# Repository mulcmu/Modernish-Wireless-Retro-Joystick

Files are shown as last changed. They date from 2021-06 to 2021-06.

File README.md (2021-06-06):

# Modernish-Wireless-Retro-Joystick
 Wii Remote & ESP32 based wireless joystick interface for Atari-style joysticks.

## Goals & Objectives:

- Support for 2 Atari style joystick DB-9 connections.  Directions, Trigger, and two analog (variable resistance) values.
- Use Wiimote, Nunchuk , gamepad for input devices.  Configurable input setup options to accommodate different homebrew hardware.  (Like Wiimote tilt sensor used like paddle controller rotation.)
- Increase distance of busy little hands from vintage hardware.

## Current Status:

See build log on [hackaday.io](https://hackaday.io/project/179786-modernish-wireless-retro-joystick)

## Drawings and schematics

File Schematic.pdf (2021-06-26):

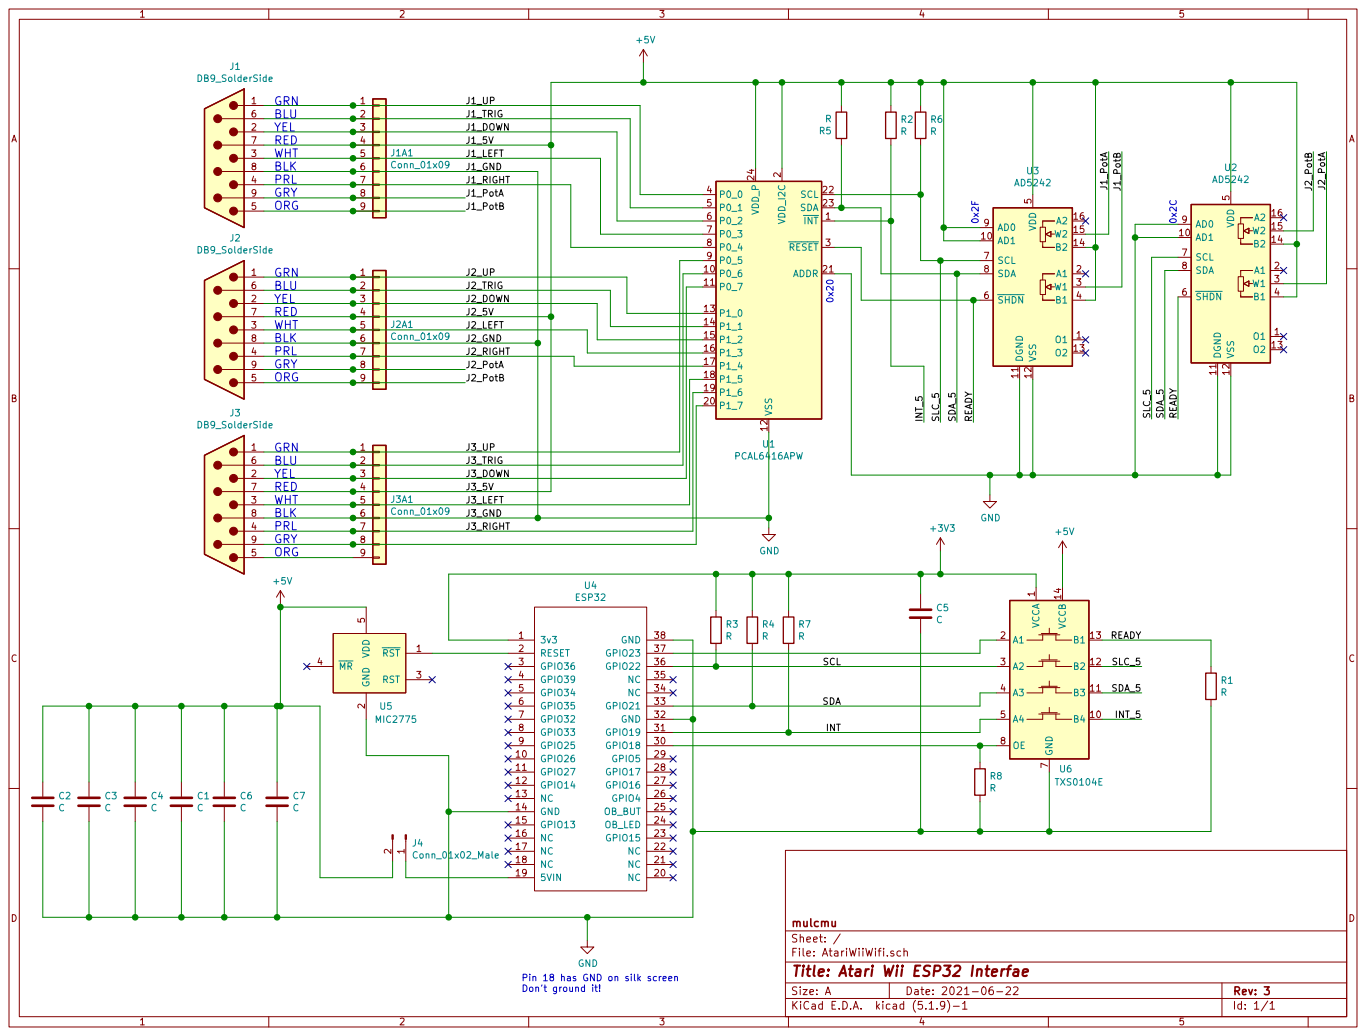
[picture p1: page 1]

J1_DOWN J1_5V

J1_LEFT J1_GND

GRN
BLU
YEL RED WHT BLK

J2_DOWN J2_5V

J2_LEFT J2_GND

J3_DOWN | GND 123456789

J3_GND

File: AtariWiiWifi.sch Sheet: / mulcmu C6 C

Id: 1/1 Title: Atari Wii ESP32 Interfae

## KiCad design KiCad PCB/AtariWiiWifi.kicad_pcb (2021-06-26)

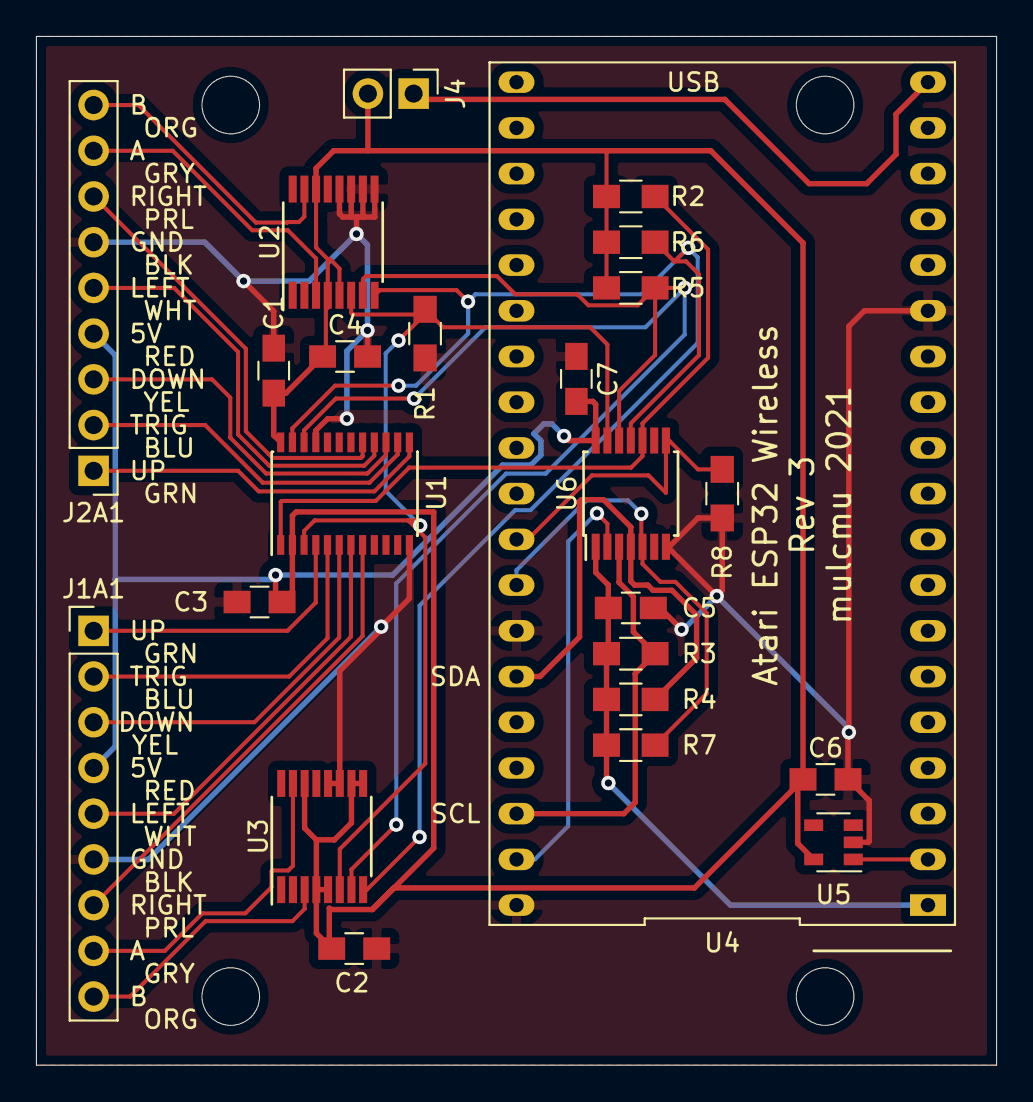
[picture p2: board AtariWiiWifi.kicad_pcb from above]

Board: 2 copper layers, 53.3 x 57.1 mm, 24 parts (0 on the bottom side), 28 nets.

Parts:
C1, C2, C3, C4, C5, C6, C7: C; C_0805_HandSoldering
J1A1, J2A1: Conn_01x09; Pin_Header_Straight_1x09_Pitch2.54mm
J4: Conn_01x02_Male; Pin_Header_Straight_1x02_Pitch2.54mm
R1, R2, R3, R4, R5, R6, R7, R8: R; R_0805_HandSoldering
U1: PCAL6416APW; TSSOP-24_4.4x7.8mm_Pitch0.65mm
U2, U3: AD5242; TSSOP-16_4.4x5mm_Pitch0.65mm
U4: ESP32; DIP-38_900_ELL
U5: MIC2775; SOT-23-5
U6: TXS0104E; TSSOP-14_4.4x5mm_Pitch0.65mm

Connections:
+3V3: C5.1, R3.1, R4.1, R7.1, U4.1, U6.1
+5V: C1.1, C2.1, C3.1, C4.1, C6.1, C7.1, J1A1.4, J2A1.4, J4.2, R2.1, R5.2, R6.1, U1.2, U1.24, U2.4, U2.5, U2.14, U3.4, U3.5, U3.9, U3.10, U3.14, U5.5, U6.14
/INT: R7.2, U4.31, U6.5
/INT_5: R2.2, U1.1, U6.10
/J1_DOWN: J1A1.3, U1.6
/J1_LEFT: J1A1.5, U1.7
/J1_PotA: J1A1.8, U3.15
/J1_PotB: J1A1.9, U3.3
/J1_RIGHT: J1A1.7, U1.8
/J1_TRIG: J1A1.2, U1.5
/J1_UP: J1A1.1, U1.4
/J2_DOWN: J2A1.3, U1.15
/J2_LEFT: J2A1.5, U1.16
/J2_PotA: J2A1.8, U2.3
/J2_PotB: J2A1.9, U2.15
/J2_RIGHT: J2A1.7, U1.17
/J2_TRIG: J2A1.2, U1.14
/J2_UP: J2A1.1, U1.13
/READY: R1.1, U1.3, U2.6, U3.6, U6.13
/SCL: R3.2, U4.36, U6.3
/SDA: R4.2, U4.33, U6.4
/SDA_5: R5.1, U1.23, U2.8, U3.8, U6.11
/SLC_5: R6.2, U1.22, U2.7, U3.7, U6.12
GND: C1.2, C2.2, C3.2, C4.2, C5.2, C6.2, C7.2, J1A1.6, J2A1.6, R1.2, R8.2, U1.12, U1.21, U2.9, U2.10, U2.11, U2.12, U3.11, U3.12, U4.14, U4.32, U4.38, U5.2, U6.7
unnamed: J4.1, U4.19
unnamed: R8.1, U4.30, U6.8
unnamed: U4.2, U5.1
unnamed: U4.37, U6.2

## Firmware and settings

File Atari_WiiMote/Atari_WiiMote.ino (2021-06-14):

#include <Wire.h> //include Wire.h library
#include <esp_types.h>

#include "ESP32Wiimote.h"
ESP32Wiimote wiimote;


#include <atomic>
using namespace std;

//i2c addresses
#define AD5242_J1_ADDRESS 0x2F
#define AD5242_J2_ADDRESS 0x2C
#define PCAL6416A_ADDRESS 0x20

//i2c commands/registers
#define AS524X_RDAC0         0x00
#define AS524X_RDAC1         0x80
#define PCAL6416A_OUTPUT_CFG 0x4F
#define PCAL6416A_DIRECTION  0x06
#define PCAL6416A_OUTPUT     0x02

byte error=0;
uint8_t i=0;
unsigned long t=0;

std::atomic<std::uint8_t> J1_btn;
std::atomic<std::uint8_t> J1_PotA;
std::atomic<std::uint8_t> J1_PotB;

std::atomic<std::uint8_t> J2_btn;
std::atomic<std::uint8_t> J2_PotA;
std::atomic<std::uint8_t> J2_PotB;


TaskHandle_t i2c_taskHandle;


//WiiMote buttons defined for vertical orientation
//Add  _H_ for horizonal orientation
#define BUTTON_H_DOWN     BUTTON_LEFT
#define BUTTON_H_UP       BUTTON_RIGHT
#define BUTTON_H_LEFT     BUTTON_UP
#define BUTTON_H_RIGHT    BUTTON_DOWN

//PCAL6416A button mapping
#define PCAL6416A_UP     0b00000001
#define PCAL6416A_DOWN   0b00000100
#define PCAL6416A_LEFT   0b00001000
#define PCAL6416A_RIGHT  0b00010000
#define PCAL6416A_TRIGR  0b00000010

void setup()
{
 J1_btn=0;
 J1_PotA=0;
 J1_PotB=0;
 J2_btn=0;
 J2_PotA=0;
 J2_PotB=0;

 
  //power up delay.
  delay(250);
  
  Wire.begin(); // Wire communication begin
  
  Serial.begin(115200); 
  //while (!Serial); // Waiting for Serial Monitor

  Serial.println("Atari WiiMote test code.");
  
  //Configure outputs as open-drain (default is push-pull)
  Wire.beginTransmission(PCAL6416A_ADDRESS);
  Wire.write(PCAL6416A_OUTPUT_CFG); 
  Wire.write(0b00000011);
  Wire.endTransmission();

  delay(100);

  //Configure P0.0 to P0.4 and P1.0 to P1.4 as outputs
  Wire.beginTransmission(PCAL6416A_ADDRESS);
  Wire.write(PCAL6416A_DIRECTION); 
  Wire.write(0b11100000);  //Port 0:  1 input, 0 output
  Wire.write(0b11100000);  //Port 1:  
  Wire.endTransmission();
  
  //create a task that will process i2c on core 0
  xTaskCreatePinnedToCore(
                    i2c_loop,       /* Task function. */
                    "i2c Loop",     /* name of task. */
                    10000,          /* Stack size of task */
                    NULL,            /* parameter of the task */
                    1,              /* priority of the task */
                    &i2c_taskHandle,/* Task handle to keep track of created task */
                    0);             /* pin task to core 0 */

    wiimote.init();
    //wiimote.addFilter(ACTION_IGNORE, FILTER_ACCEL); // optional
 
}

//Standard loop handles wiiMote on Core 1
void loop()
{
    wiimote.task();
  if (wiimote.available() > 0) 
    {
      ButtonState  button  = wiimote.getButtonState();
      
      (button & BUTTON_H_UP)    ?    J1_btn |= PCAL6416A_UP     :  J1_btn &= ~PCAL6416A_UP;
      (button & BUTTON_H_DOWN)  ?    J1_btn |= PCAL6416A_DOWN   :  J1_btn &= ~PCAL6416A_DOWN;
      (button & BUTTON_H_LEFT)  ?    J1_btn |= PCAL6416A_LEFT   :  J1_btn &= ~PCAL6416A_LEFT;
      (button & BUTTON_H_RIGHT) ?    J1_btn |= PCAL6416A_RIGHT  :  J1_btn &= ~PCAL6416A_RIGHT;
      (button & BUTTON_TWO)     ?    J1_btn |= PCAL6416A_TRIGR  :  J1_btn &= ~PCAL6416A_TRIGR;
      
      J2_btn.store(J1_btn.load());

      

      if (button & BUTTON_HOME) {
        J1_PotA = 128;
        J1_PotB = 128;
        J2_PotA = 128;
        J2_PotB = 128;
      }

      if (J1_PotA < 253 && button & BUTTON_PLUS) {
        J1_PotA++;
        J1_PotB++;
        J2_PotA++;
        J2_PotB++;
      }

      if (J1_PotA > 3 && button & BUTTON_MINUS){
        J1_PotA--;
        J1_PotB--;
        J2_PotA--;
        J2_PotB--;
      }

    Serial.println(J1_btn);
    Serial.println(J1_PotA);

      
    }

}



void wiiMote_Debug(void)  {
  if (wiimote.available() > 0) 
    {
        ButtonState  button  = wiimote.getButtonState();
        AccelState   accel   = wiimote.getAccelState();
        NunchukState nunchuk = wiimote.getNunchukState();

        if (1)
        {
            char ca     = (button & BUTTON_A)     ? 'A' : '.';
            char cb     = (button & BUTTON_B)     ? 'B' : '.';
            char cc     = (button & BUTTON_C)     ? 'C' : '.';
            char cz     = (button & BUTTON_Z)     ? 'Z' : '.';
            char c1     = (button & BUTTON_ONE)   ? '1' : '.';
            char c2     = (button & BUTTON_TWO)   ? '2' : '.';
            char cminus = (button & BUTTON_MINUS) ? '-' : '.';
            char cplus  = (button & BUTTON_PLUS)  ? '+' : '.';
            char chome  = (button & BUTTON_HOME)  ? 'H' : '.';
            char cleft  = (button & BUTTON_LEFT)  ? '<' : '.';
            char cright = (button & BUTTON_RIGHT) ? '>' : '.';
            char cup    = (button & BUTTON_UP)    ? '^' : '.';
            char cdown  = (button & BUTTON_DOWN)  ? 'v' : '.';
      
            Serial.printf("button: %05x = ", (int)button);
            Serial.print(ca);
            Serial.print(cb);
            Serial.print(cc);
            Serial.print(cz);
            Serial.print(c1);
            Serial.print(c2);
            Serial.print(cminus);
            Serial.print(chome);
            Serial.print(cplus);
            Serial.print(cleft);
            Serial.print(cright);
            Serial.print(cup);
            Serial.print(cdown);
            Serial.printf(", wiimote.axis: %3d/%3d/%3d", accel.xAxis, accel.yAxis, accel.zAxis);
            Serial.printf(", nunchuk.axis: %3d/%3d/%3d", nunchuk.xAxis, nunchuk.yAxis, nunchuk.zAxis);
            Serial.printf(", nunchuk.stick: %3d/%3d\n", nunchuk.xStick, nunchuk.yStick);
        }
    }
}




//i2c loop runs on core 0
void i2c_loop( void * pvParameters ){
  //Serial.print("i2c running on core ");
  //Serial.println(xPortGetCoreID());

  for(;;){
    Wire.beginTransmission(AD5242_J1_ADDRESS);
    Wire.write(AS524X_RDAC0);
    Wire.write(J1_PotA);
    Wire.endTransmission();
    
    Wire.beginTransmission(AD5242_J1_ADDRESS);
    Wire.write(AS524X_RDAC1);
    Wire.write(J1_PotB);
    Wire.endTransmission();

      
    Wire.beginTransmission(AD5242_J2_ADDRESS);
    Wire.write(AS524X_RDAC0);
    Wire.write(J2_PotA);
    Wire.endTransmission();

    
    Wire.beginTransmission(AD5242_J2_ADDRESS);
    Wire.write(AS524X_RDAC1);
    Wire.write(J2_PotB);
    Wire.endTransmission();

    Wire.beginTransmission(PCAL6416A_ADDRESS);
    Wire.write(PCAL6416A_OUTPUT); //Output Register
    Wire.write(~J1_btn);  //Port 0
    Wire.write(~J2_btn);  //Port 1  
    Wire.endTransmission();

  }
}

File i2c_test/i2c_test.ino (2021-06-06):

#include <Wire.h> //include Wire.h library

#define AD5242_J1_ADDRESS 0x2F
#define AD5242_J2_ADDRESS 0x2C
#define PCAL6416A_ADDRESS 0x20

#define AS524X_RDAC0    0x00
#define AS524X_RDAC1    0x80

byte error=0;

uint8_t i=0;

unsigned long t=0;

void setup()
{
  Wire.begin(); // Wire communication begin
  
  Serial.begin(115200); 
  while (!Serial); // Waiting for Serial Monitor

  Serial.println("i2c test code.");

  //Configure P0.0 to P0.4 and P1.0 to P1.4 as outputs
  Wire.beginTransmission(PCAL6416A_ADDRESS);
  Wire.write(0x06); //Direction Register
  Wire.write(0b11100000);  //Port 0:  1 input, 0 output
  Wire.write(0b11100000);  //Port 1:  
  //Serial.println(Wire.endTransmission());

 
}

void loop()
{

  t=millis();

  for(i=0; i<255; i++) {
  
    Wire.beginTransmission(AD5242_J1_ADDRESS);
    Wire.write(AS524X_RDAC0);
    Wire.write(i);
    error = Wire.endTransmission();
    //Serial.println(error);
    
    Wire.beginTransmission(AD5242_J1_ADDRESS);
    Wire.write(AS524X_RDAC1);
    Wire.write(i);
    error = Wire.endTransmission();
    //Serial.println(error);
      
    Wire.beginTransmission(AD5242_J2_ADDRESS);
    Wire.write(AS524X_RDAC0);
    Wire.write(i);
    error = Wire.endTransmission();
    //Serial.println(error);
    
    Wire.beginTransmission(AD5242_J2_ADDRESS);
    Wire.write(AS524X_RDAC1);
    Wire.write(i);
    error = Wire.endTransmission();
    //Serial.println(error);
  
    Wire.beginTransmission(PCAL6416A_ADDRESS);
    Wire.write(0x02); //Output Register
    Wire.write(i);  //Port 0
    Wire.write(i);  //Port 1  
    error = Wire.endTransmission();
    //Serial.println(error);

  }

  Serial.println(millis()-t);

  delay(2000); // wait 2 to increment
}

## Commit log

2021-05-15 Rev1 PCB
    [AtariWiiWifi-B_Cu.gbr, AtariWiiWifi-B_Mask.gbr, AtariWiiWifi-B_Paste.gbr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]
2021-06-06 Add i2c_test Ardunio Code
    Add test code used to test basic board operation.
2021-06-09 Update PCB to Rev 2
    Fixed Digital pots connected to ground instead of +5.
    Added jumper to power ESP from Atari
    [AtariWiiWifi-B_Cu.gbr, AtariWiiWifi-B_Mask.gbr, AtariWiiWifi-B_Paste.gbr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]
2021-06-18 Update Schematic.pdf
    Rev 2.1 testing for i2c level shifting
2021-06-23 Update Schematic.pdf
    Rev 3
2021-06-26 Rev 3 PCB
    Update Rev 3 PCB files.
    Small Tweak to Schematic for extra bypass cap.
    [AtariWiiWifi-B_Cu.gbr, AtariWiiWifi-B_Mask.gbr, AtariWiiWifi-B_Paste.gbr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]
